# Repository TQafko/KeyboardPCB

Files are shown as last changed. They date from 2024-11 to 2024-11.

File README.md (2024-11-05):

# KeyboardPCB
The project aimed to create a Human Interface Device (HID) using an Arduino microcontroller with the Atmega32U4 chip. The keyboard was to be used for additional keys to a laptop to allow the user easier access to certain characters; adding a numeric numpad. As computers use drivers to understand what external USB devices are trying to communicate, this device was designed and programmed to send ASCI characters through the USB2.0 protocol.

## Comarpison of Atmega328 vs Atmega32U4
Due to HID devices requiring a USB interface a microcontroller using the Atmega 32U4 chip was selected. By comparing the two functional block diagrams below of the two chips, the Atmega 32U4 contains the USB2.0 block that allows the computer to directly communicate via USB to the chip and therefore not requiring a USB-to-Serial converter on board.  

## 3D Model
keyboard_3dmodel
## Schematics
keyboard_schem
## Layout
keyboard_layout

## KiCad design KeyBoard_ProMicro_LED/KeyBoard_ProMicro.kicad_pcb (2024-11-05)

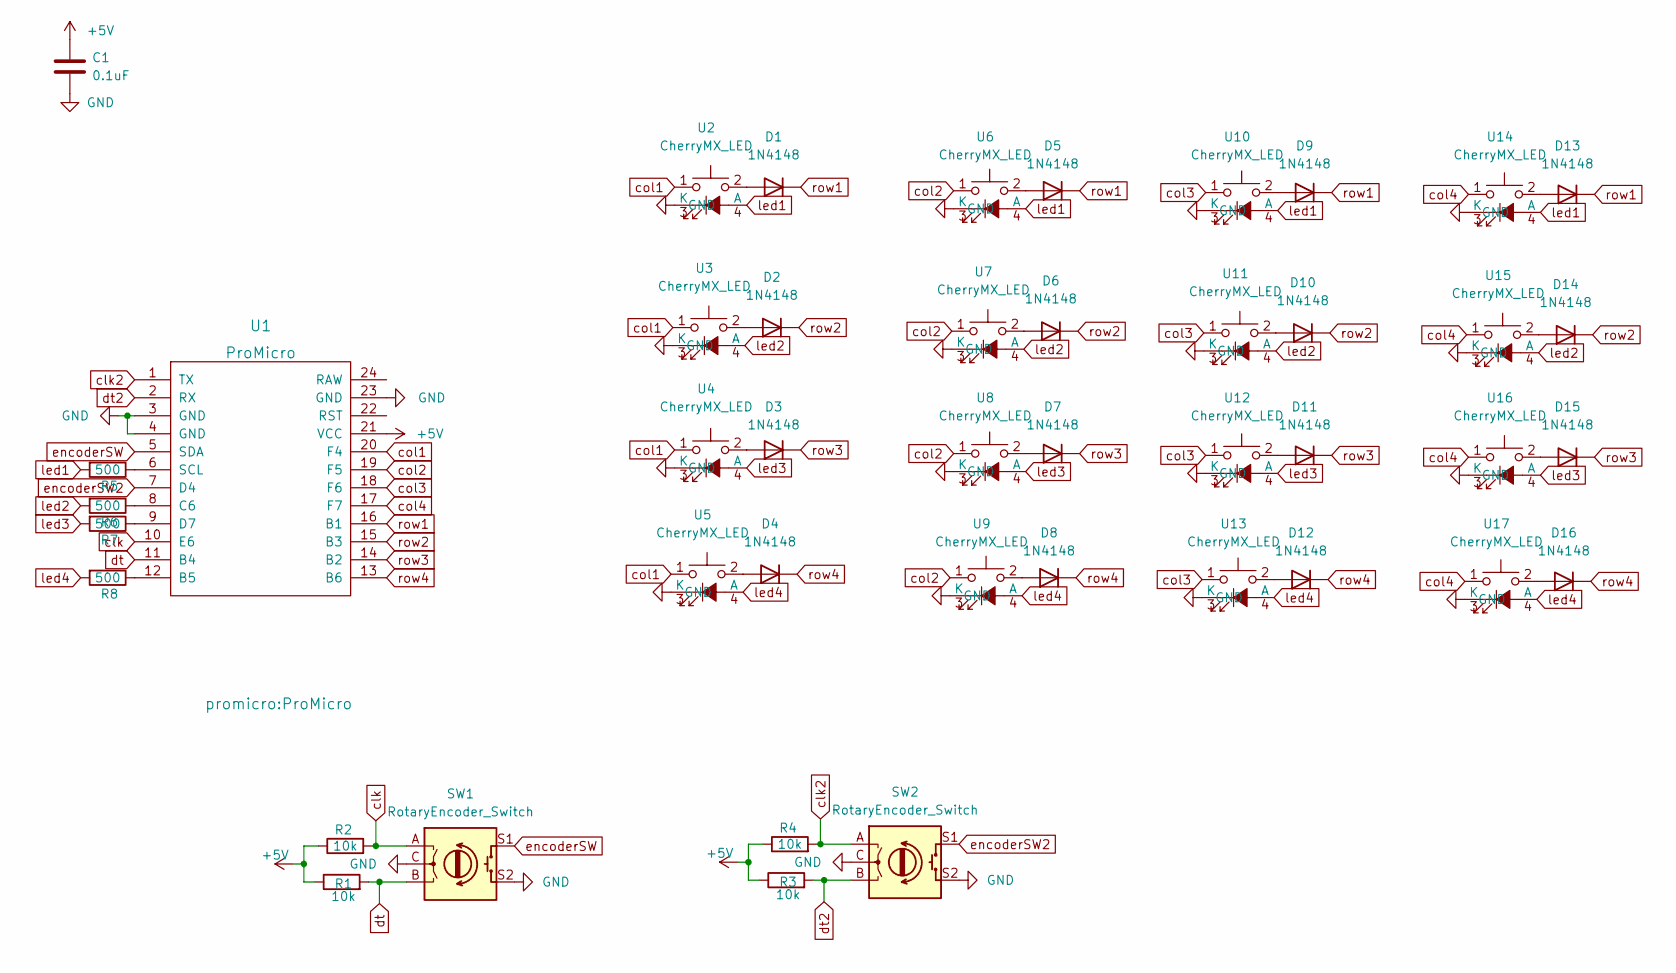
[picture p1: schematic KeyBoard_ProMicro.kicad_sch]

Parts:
C1: 0.1uF; C_1206_3216Metric
D1, D2, D3, D4, D5, D6, D7, D8, D9, D10, D11, D12, D13, D14, D15, D16: 1N4148; D_DO-35_SOD27_P7.62mm_Horizontal
R1, R2, R3, R4: 10k; R_Axial_DIN0207_L6.3mm_D2.5mm_P10.16mm_Horizontal
R5, R6, R7, R8: 500; R_Axial_DIN0207_L6.3mm_D2.5mm_P10.16mm_Horizontal
SW1, SW2: RotaryEncoder_Switch; RotaryEncoder_Alps_EC12E-Switch_Vertical_H20mm
U1: ProMicro
U2, U3, U4, U5, U6, U7, U8, U9, U10, U11, U12, U13, U14, U15, U16, U17: CherryMX_LED; CherryMX_1.00u_PCB_LED

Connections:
+5V: C1.1, R1.1, R2.1, R3.1, R4.1, U1.21 (VCC)
GND: C1.2, SW1.C, SW1.S2, SW2.C, SW2.S2, U1.3 (GND), U1.4 (GND), U1.23 (GND), U2.3 (K), U3.3 (K), U4.3 (K), U5.3 (K), U6.3 (K), U7.3 (K), U8.3 (K), U9.3 (K), U10.3 (K), U11.3 (K), U12.3 (K), U13.3 (K), U14.3 (K), U15.3 (K), U16.3 (K), U17.3 (K)
unnamed: D1.2 (A), U2.2
unnamed: D2.2 (A), U3.2
unnamed: D3.2 (A), U4.2
unnamed: D4.2 (A), U5.2
unnamed: D5.2 (A), U6.2
unnamed: D6.2 (A), U7.2
unnamed: D7.2 (A), U8.2
unnamed: D8.2 (A), U9.2
unnamed: D9.2 (A), U10.2
unnamed: D10.2 (A), U11.2
unnamed: D11.2 (A), U12.2
unnamed: D12.2 (A), U13.2
unnamed: D13.2 (A), U14.2
unnamed: D14.2 (A), U15.2
unnamed: D15.2 (A), U16.2
unnamed: D16.2 (A), U17.2
unnamed: R5.1, U1.6 (SCL)
unnamed: R6.1, U1.8 (C6)
unnamed: R7.1, U1.9 (D7)
unnamed: R8.1, U1.12 (B5)
clk: R2.2, SW1.A, U1.10 (E6)
clk2: R4.2, SW2.A, U1.1 (TX)
col1: U1.20 (F4), U2.1, U3.1, U4.1, U5.1
col2: U1.19 (F5), U6.1, U7.1, U8.1, U9.1
col3: U1.18 (F6), U10.1, U11.1, U12.1, U13.1
col4: U1.17 (F7), U14.1, U15.1, U16.1, U17.1
dt: R1.2, SW1.B, U1.11 (B4)
dt2: R3.2, SW2.B, U1.2 (RX)
encoderSW: SW1.S1, U1.5 (SDA)
encoderSW2: SW2.S1, U1.7 (D4)
led1: R5.2, U2.4 (A), U6.4 (A), U10.4 (A), U14.4 (A)
led2: R6.2, U3.4 (A), U7.4 (A), U11.4 (A), U15.4 (A)
led3: R7.2, U4.4 (A), U8.4 (A), U12.4 (A), U16.4 (A)
led4: R8.2, U5.4 (A), U9.4 (A), U13.4 (A), U17.4 (A)
row1: D1.1 (K), D5.1 (K), D9.1 (K), D13.1 (K), U1.16 (B1)
row2: D2.1 (K), D6.1 (K), D10.1 (K), D14.1 (K), U1.15 (B3)
row3: D3.1 (K), D7.1 (K), D11.1 (K), D15.1 (K), U1.14 (B2)
row4: D4.1 (K), D8.1 (K), D12.1 (K), D16.1 (K), U1.13 (B6)

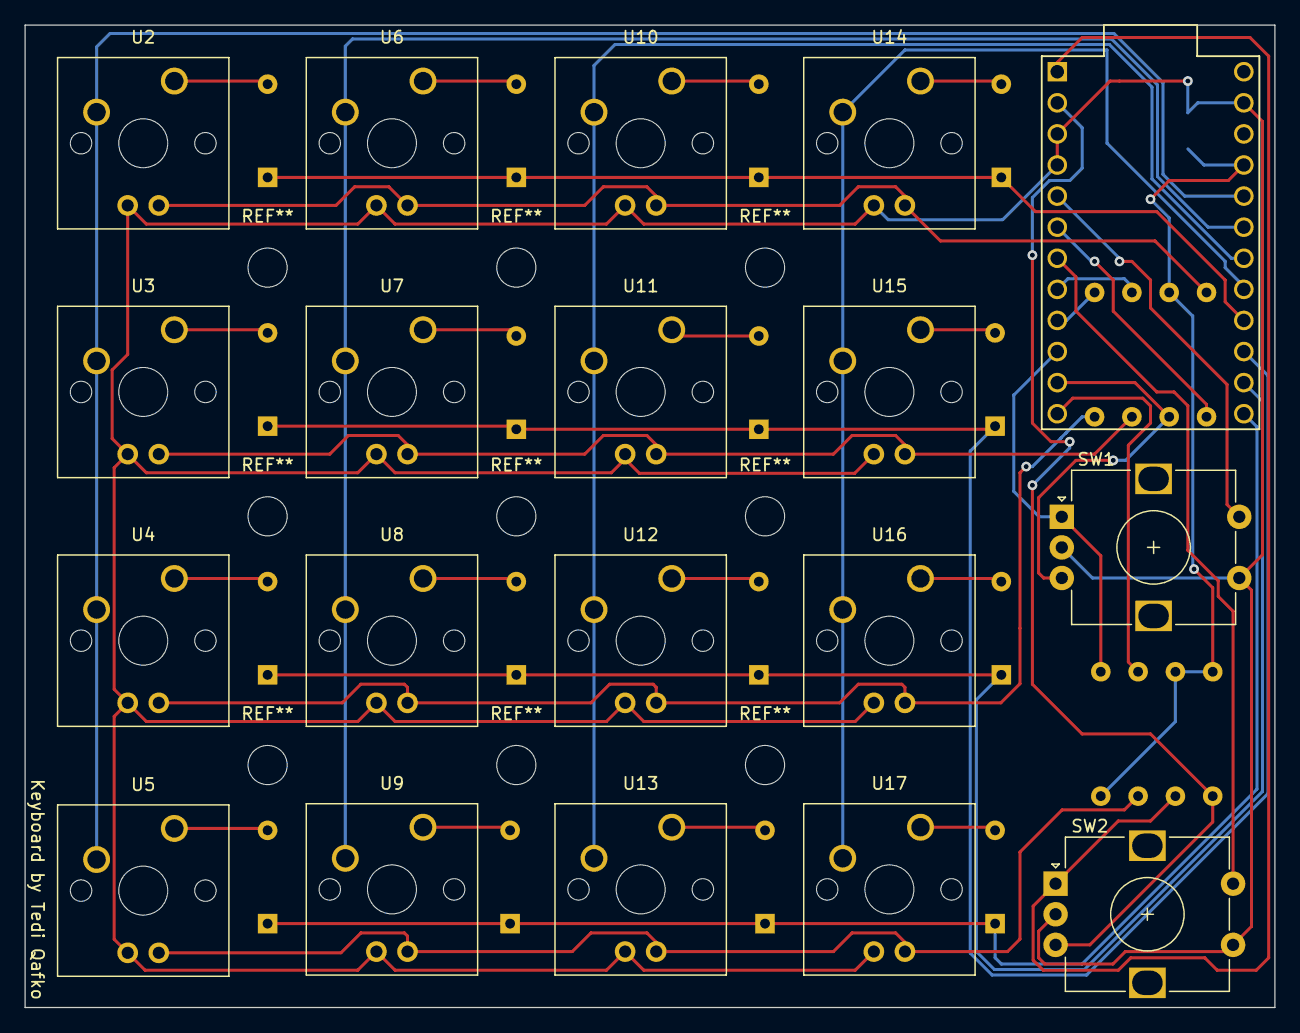
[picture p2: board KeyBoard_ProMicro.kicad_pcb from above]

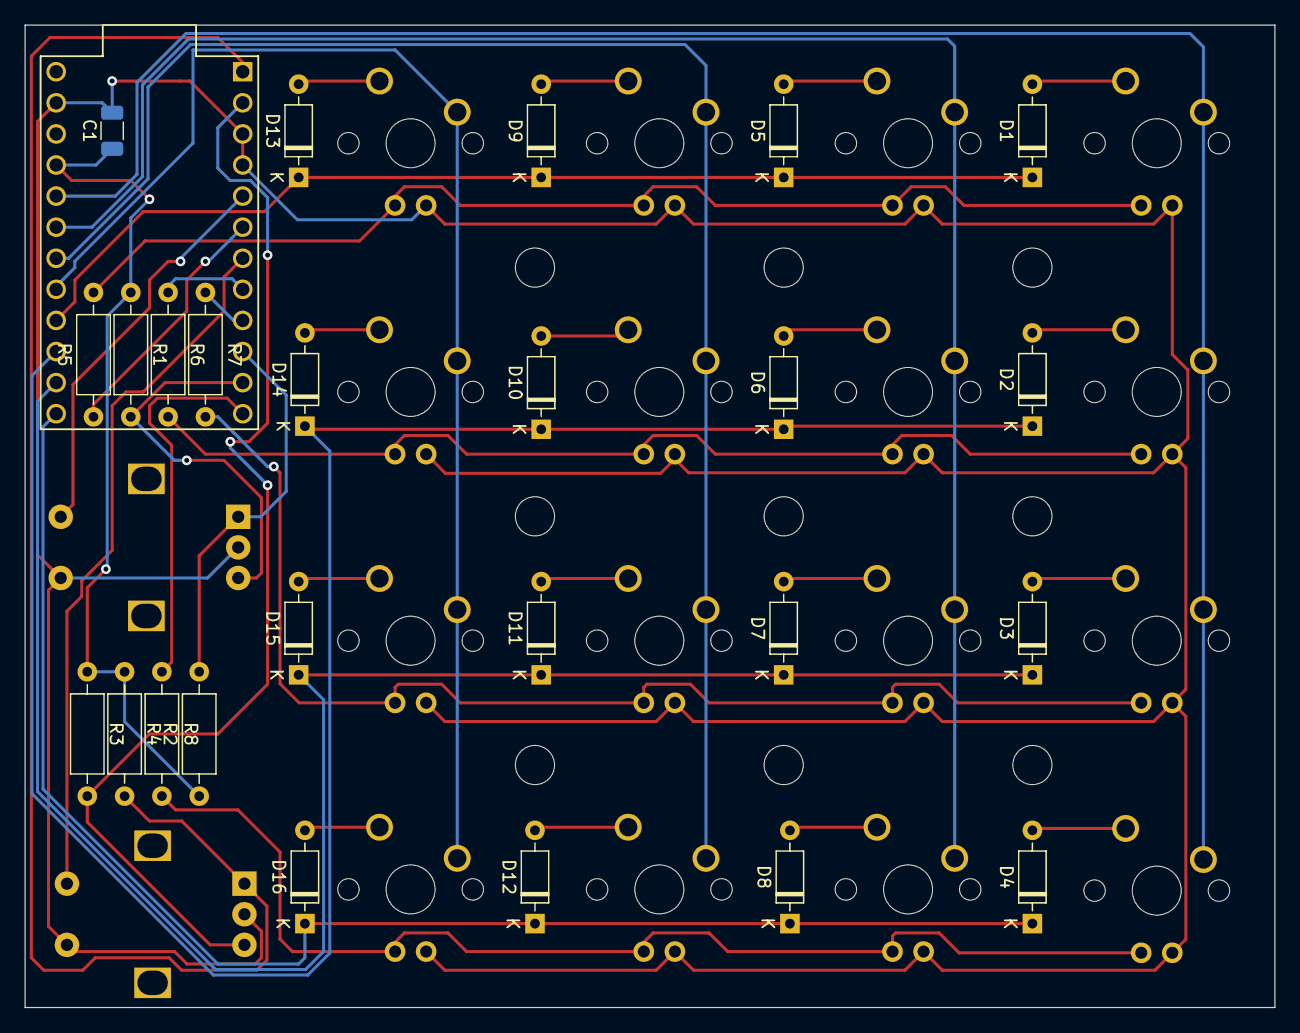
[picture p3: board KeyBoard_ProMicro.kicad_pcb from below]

Board: 2 copper layers, 102.1 x 80.3 mm, 44 parts (25 on the bottom side), 40 nets.

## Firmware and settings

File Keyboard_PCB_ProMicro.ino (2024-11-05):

#include "Keyboard.h" 
#include <Encoder.h>

int longPressDelay = 350;           //customizable keyboard values
int spamSpeed = 15;

byte inputs[] = {18,19,20,21};
#define inCount sizeof(inputs)/sizeof(inputs[0])
byte outputs[] = {10,16,14,15};
#define outCount sizeof(outputs)/sizeof(outputs[0])

char layout[outCount][inCount] = {               //layout grid for characters (adjust if your grid is not 4x4)
  {'/','*','+','-'},
  {'9','6','3',176}, //176 is for return or enter
  {'8','5','2','0'},
  {'7','4','1','.'},
};

int keyDown[outCount][inCount];
bool keyLong[outCount][inCount]; 

Encoder knobLeft(7, 8);
Encoder knobRight(1, 0);
long positionLeft  = -999;
long positionRight = -999;

void setup(){
  
  for(int i=0; i<outCount; i++){    //declaring all the outputs and setting them high
    pinMode(outputs[i],OUTPUT);
    digitalWrite(outputs[i],HIGH);
  }
  for(int i=0; i<inCount; i++){     //declaring all the inputs and activating the internal pullup resistor
    pinMode(inputs[i],INPUT_PULLUP);
  }
  
  Serial.begin(9600);               //establishing Serial link and initializing keyboard
  Serial.println("Connected");
  Keyboard.begin();
  
}

//Main loop going through all the keys, then waiting 0.5ms
void loop() {
  for (int i=0; i<outCount; i++)
  {    
    digitalWrite(outputs[i],LOW);   //setting one row low
    delayMicroseconds(5);           //giving electronics time to settle down
    
    for(int j=0; j<inCount; j++)
    {
      if(digitalRead(inputs[j]) == LOW)
      {
        keyPressed(i,j);            //calling keyPressed function if one of the inputs reads low
      }
      else if(keyDown[i][j] != 0)   //resetting the key if it is not pressed any more
      {  
        resetKey(i,j);
      }
    }
    
    digitalWrite(outputs[i],HIGH);
    delayMicroseconds(500);         //setting the row high and waiting 0.5ms until next cycle
  }
  long newLeft, newRight;
  newLeft = knobLeft.read();
  newRight = knobRight.read();
  if (newLeft != positionLeft || newRight != positionRight) {
    Serial.print("Left = ");
    Serial.print(newLeft);
    Serial.print(", Right = ");
    Serial.print(newRight);
    Serial.println();
    positionLeft = newLeft;
    positionRight = newRight;
  }
  // if a character is sent from the serial monitor,
  // reset both back to zero.
  if (Serial.available()) {
    Serial.read();
    Serial.println("Reset both knobs to zero");
    knobLeft.write(0);
    knobRight.write(0);
  }
  
}

//if a key is pressed, this Funtion is called and outputs to serial the key location, it also sends the keystroke if not already done so
void keyPressed(int row, int col){
  Serial.print("Output: "); 
  Serial.print(row);
  Serial.print(" Input: ");
  Serial.print(col);
  Serial.print(" ");
  Serial.println(layout[row][col]);

  if(keyDown[row][col]==0){         //if the function is called for the first time for this key
    Keyboard.write(layout[row][col]);
  }
  else if(keyLong[row][col] && keyDown[row][col] > spamSpeed){ //if the key has been held long enough to warrant another keystroke set
    Keyboard.write(layout[row][col]);
    keyDown[row][col] = 1;
  }
  else if(keyDown[row][col] > longPressDelay){ //if the key has been held for longer that longPressDelay, it switches into spam mode
    keyLong[row][col] = true;
  }

  keyDown[row][col]++;
}

void resetKey(int row, int col){ //resetting the variables after key is released
  keyDown[row][col] = 0;
  keyLong[row][col] = false;
}
